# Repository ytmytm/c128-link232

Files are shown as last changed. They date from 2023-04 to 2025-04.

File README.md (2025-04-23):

These are boards for C128D/DCR internal WiFi modems based on the ACIA 6551 and Wemos D1 ESP8266 modules flashed with Zimodem firmware.

This work is heavily base on dabonetn's work from [Link232-Wifi](https://github.com/dabonetn/Link232-Wifi) project. Please go there for additional documentation.

# Installation

For both projects you need to decide on the interrupt source and address space. I recommend using `/NMI` as the interrupt and `$D700` as the base address.
This way, you can readily use most popular software for both C128 (DesTerm) and C64 (CCGMS), and the mod doesn't interfere with cartridges.

## Raise CIA

For both boards one of the CIA chips is raised to the daughterboard.

## Interrupt line

Both boards connect ACIA interrupt pin to local CIA chip but if it's not the right one (i.e. you want `/NMI` but the board is over CIA#1 which is connected to `/IRQ`) you need to run a wire to a suitable singal source from the mainboard.

## Base address

A signal for ACIA I/O address access in $D700-$D7FF area is readily available from U3 pin 12 that is otherwise unconnected.

## DotClock

Both boards require DotClock signal from the Expansion port pin 6.

# Swift-L (C128D)

This board is meant primarly for C128D and it is supposed to be plugged in place of CIA#2. It is a clone of [Link232 Swift-L](https://github.com/dabonetn/Link232-Wifi) project converted to Kicad6, with Burst connector added.

The `/NMI` signal is already available from the mainboard CIA#2 socket, so you only need to connect ACIA I/O signal and DotClock.

This board also features a 10-pin socket for a flat cable for burst connection to 1541 drives. The pinout is compatible with [DolphinDos3](https://e4aws.silverdr.com/projects/dolphindos3/) with `/FLAG` signal on pin 1, then 8 data lines and `/PC2` signal on pin 10. 

## C128DCR notes

There is not enough clearance under power supply on C128DCR to use that board with CIA#2, but this should fit in place of CIA#1.

You need to route `/NMI` interrupt line to pin 26 of ACIA 6551 somewhere from the board - the Expansion port pin D is the closet spot.

The burst connector would work correctly, but no software uses CIA#1 for that purpose.

## Swift-CIA3 (C128DCR)

This board is meant to be used in C128DCR over CIA#1. It has several features that I needed and you may find optional. If all you need is internal ACIA modem you should better use Swift-L variant.

You need to connect these external control signals to connector J1:

|pin|  |
|---|--|
|1|I/O signal for ACIA, for page $D700 connect to U3 pin 12|
|2|DotClock from Expansion port pin 6|
|3|Interrupt for ACIA, connect `/NMI` from Expansion port pin D|
|4|I/O signal for CIA#3 (optional)

In my case both ACIA I/O and CIA#3 I/O signals come from [U3 address decoder replaced by a GAL](https://github.com/ytmytm/c128-u3-replacement), so CIA#1 occupies addresses $DC00-$DC20 and CIA#3 appears in $DC20-$DC40

Connector J2 has a simple serial bus with GND/VCC/SP/CNT signals from CIA#3.

Connector J4 exposes CIA#3 port B so that it can be used to switch Kernal or Internal Function ROMs.

A jumper controls whether ACIA is connected to `/IRQ` (from CIA#1) or to `/NMI` (from J1 pin 3).

Another jumper selects 50/60Hz signal for TOD clock coming from ATTiny.

### CIA#3

CIA#3 is connected to ATA-IDE 40-pin connector for harddrives for [my CIAIDE project](https://github.com/ytmytm/c64-ciaide).
Port B lines are also connected to a pin header because they could be used for something like an internal ROM switcher.

### ATTiny85

There is a place for ATTiny85 to generate TOD clock signal.

In one of my C128DCRs I replaced power supply by a Mean Well RD35A power supply with 12V(1A)/5V(4A) rails. This runs much cooler than original power supply, but doesn't generate 9VAC. I don't mind the tape port as I don't use it anyway, but TOD clock is useful for GEOS.

Note that without 9VAC you need to replace CR8 by a wire (to short it to GND so that input to U16 pin 11 is not floating) and completely remove R7 and C80 elements.

**NOTE Don't use this sketch! Use the [more accurate code by fastjack](https://github.com/fastjack/attiny-clockgen)**

ATTiny runs this simple Arduino code to generate 50/60Hz waveform on TOD clock line, depending on jumper being open or closed:

```

// IDE: ATtiny25/45/85, internal 1MHz
// 1MHz is the default speed, no need to switch fuses to 8MHz
// compile to HEX (Sketch->Export compiled binary) and burn using TL866-II

// pinout
//   /RESET 1  U  8 5V
//   A3/PB3 2     7 A1/2/PB2
//   A2/PB4 3     6 PB1 PWM
//      GND 4     5 PB0 PWM -- output PWM 50Hz

const uint8_t PWM_pin = 0; // PB0, pin 5
const uint8_t mode_pin = 1; // PB1, pin 6 - jumper to GND for NTSC mode, keep floating (internal pullup) for PAL
uint8_t half_duty = 10;    // 10ms for PAL, 8ms for NTSC = 20ms/16ms

void setup() {
  pinMode(PWM_pin, OUTPUT);
  digitalWrite(PWM_pin, LOW);
  pinMode(mode_pin, INPUT_PULLUP);
  delay(200);
  if (digitalRead(mode_pin) == LOW) { // is it tied to GND?
    half_duty = 8;  // yes - switch to 8ms half duty cycle for 16ms ~ 62.5Hz frequency
  }
}

void loop() {
  // could be done using PWM and clock prescalers, but that is good enough for me
  while (true) {
    delay(half_duty); // 10ms - half of 20ms duty cycle
    digitalWrite(PWM_pin, HIGH);
    delay(half_duty); // 10ms - half of 20ms duty cycle
    digitalWrite(PWM_pin, LOW);
  }
}

```

# Zimodem - Wemos D1 firmware

Flash Wemos D1 with [Zimodem](https://github.com/bozimmerman/Zimodem) software.

I have compiled it with these settings:

Board: LOLIN(WEMOS) D1 R2 & Mini, 80MHz, flash 4MB (2MB FS, 1MB OTA), debug disabled, lwIP "v2 Lower Memory", Erase Flash: "Only sketch"

*Attention*: Check if this notice still exists in the README. If it does - make sure to downgrade Generic ESP8266 Library to version 2.7.4 in your Arduino IDE.

```
2.7.4 Arduino ESP8266 libraries using the Generic ESP8266 Module.  Versions newer than 2.7.4 may not work.
```

"May not work" in this case means that ESP8266 will keep crashing. You can test this still in Arduino IDE in the serial monitor.

*Attention*: Search for these defines and make these changes on the top of zimodem.ino before compiling:

1. Comment out this line to make RS232 lines non-inverted by default:
```
//# define RS232_INVERTED 1
```

2. Set default baud rate to 19200 (sensible choice for C64) or 38400 (maximum for ACIA)
```
#define DEFAULT_BAUD_RATE 19200
```

# C64/128 software

With these changes and ACIA setup to use `/NMI` at $D700 base address both latest version of CCGMS and DesTerm 128 will work fine.

Make sure that everything is setup correctly by issuing `AT` command. The modem should respond with `OK`.

Then start configuration menu by typing `AT+CONFIG`

By default RTS/CTS flow control is not enabled (so that operation can be checked in Arduino IDE serial monitor), so you should enable it with `ATF0` command because C64/128 will not keep up with scrolling the screen even in 19200 baud mode. You can save the settings to flash afterwards with `AT&W`.

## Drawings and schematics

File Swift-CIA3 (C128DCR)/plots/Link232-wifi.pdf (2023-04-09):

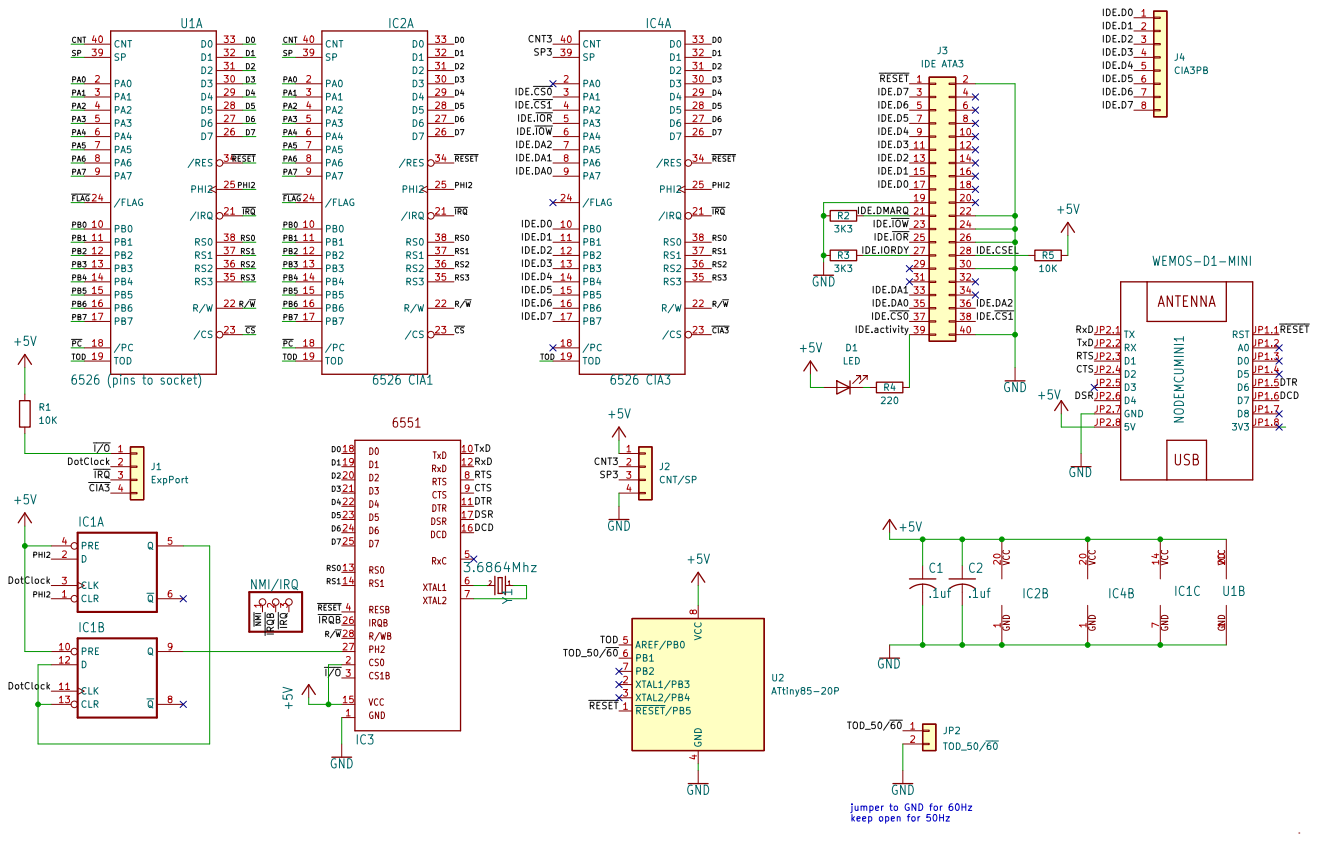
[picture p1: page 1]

jumper to GND for 60Hz
keep open for 50Hz

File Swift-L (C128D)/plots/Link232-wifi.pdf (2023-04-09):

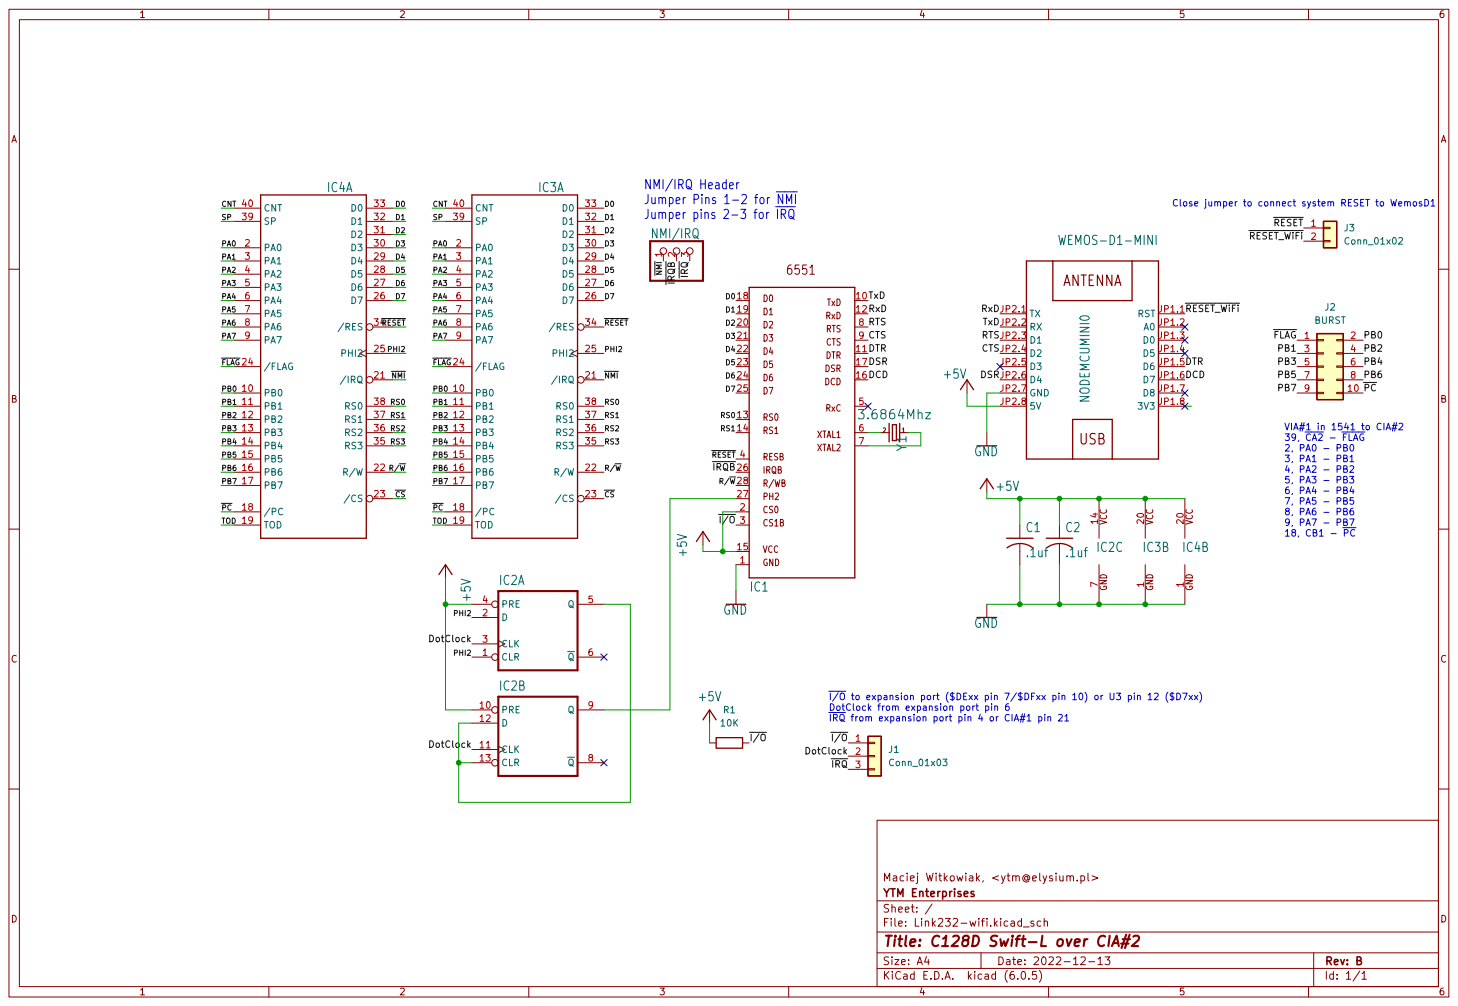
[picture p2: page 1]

Close jumper to connect system RESET to WemosD1
WEMOS-D1-MINI GND 14VCC

~{I/O} to expansion port ($DExx pin 7/$DFxx pin 10) or U3 pin 12 ($D7xx)
DotClock from expansion port pin 6
~{IRQ} from expansion port pin 4 or CIA#1 pin 21

File: Link232-wifi.kicad_sch Sheet: / YTM Enterprises

Id: 1/1 Title: C128D Swift-L over CIA#2

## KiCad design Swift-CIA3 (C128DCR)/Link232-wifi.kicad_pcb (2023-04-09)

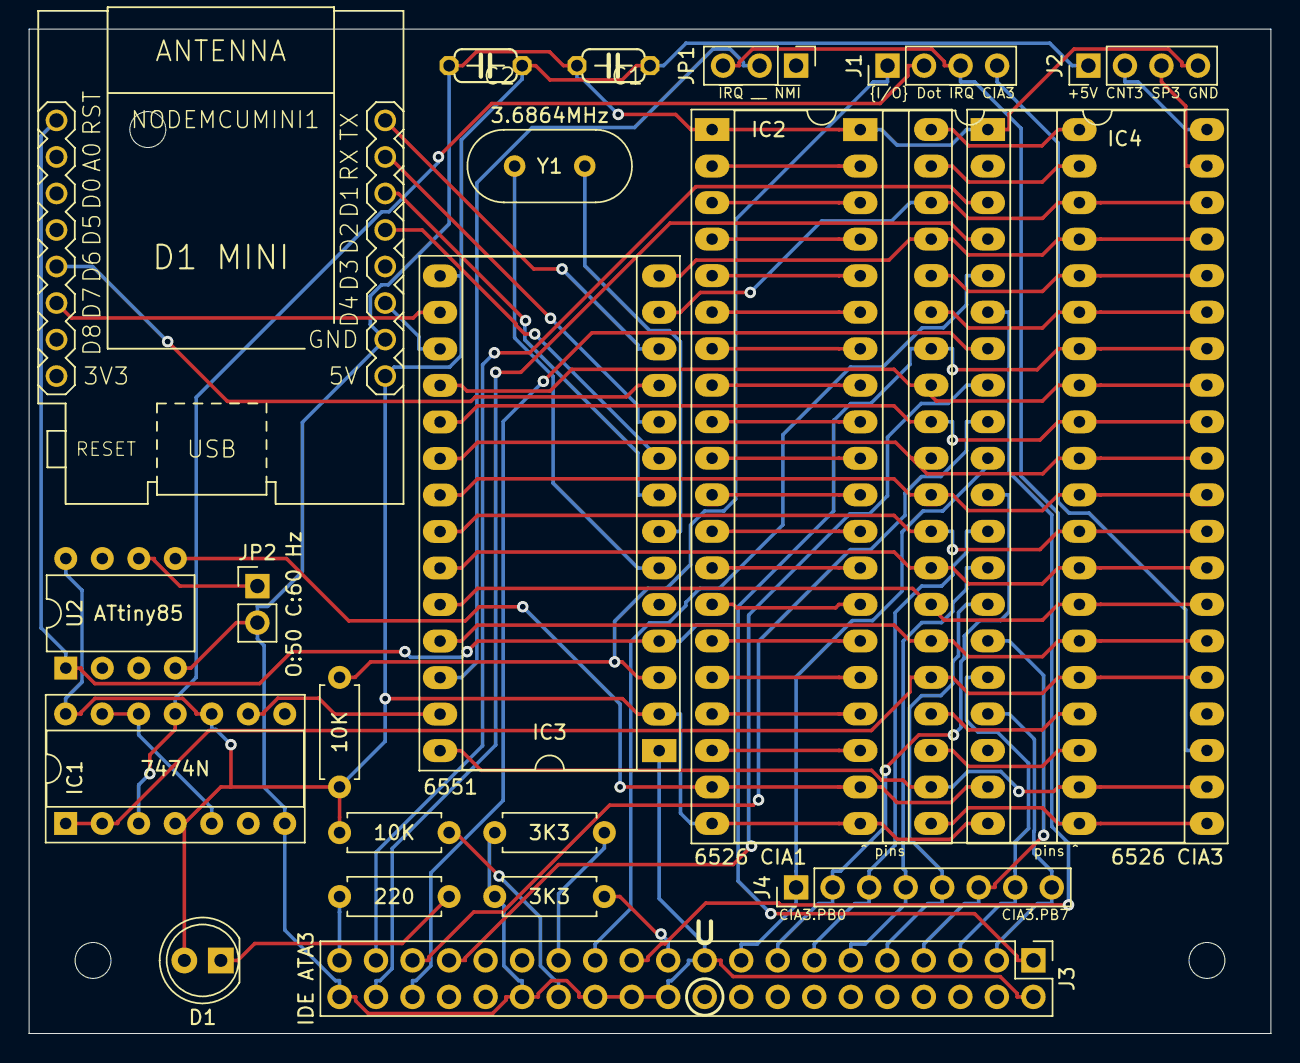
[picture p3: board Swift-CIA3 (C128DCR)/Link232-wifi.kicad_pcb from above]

Board: 2 copper layers, 86.4 x 69.8 mm, 25 parts (0 on the bottom side), 78 nets.

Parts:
C1, C2: .1uf; C050-024X044
D1: LED; LED_D5.0mm
IC1: 7474N; DIP-14_W7.62mm_Socket
IC2: 6526 CIA1; DIP-40_W15.24mm_Socket_LongPads
IC3: 6551; DIP-28_W15.24mm_Socket_LongPads
IC4: 6526 CIA3; DIP-40_W15.24mm_Socket_LongPads
J1: {I/O} Dot ~{IRQ} ~{CIA3}; PinHeader_1x04_P2.54mm_Vertical
J2: +5V CNT3 SP3 GND; PinHeader_1x04_P2.54mm_Vertical
J3: IDE ATA3; PinHeader_2x20_P2.54mm_Vertical
J4: CIA3PB; PinHeader_1x08_P2.54mm_Vertical
JP1: ~{IRQ} __ ~{NMI}; PinHeader_1x03_P2.54mm_Vertical
JP2: O:50 C:60 Hz; PinHeader_1x02_P2.54mm_Vertical
NODEMCUMINI1: WEMOS-D1-MINI
R1, R5: 10K; R_Axial_DIN0207_L6.3mm_D2.5mm_P7.62mm_Horizontal
R2, R3: 3K3; R_Axial_DIN0207_L6.3mm_D2.5mm_P7.62mm_Horizontal
R4: 220; R_Axial_DIN0207_L6.3mm_D2.5mm_P7.62mm_Horizontal
REF1, REF2, REF3: MountingHole_2.5mm
U1: 6526 (pins to socket); DIP-40_W15.24mm_LongPads
U2: ATtiny85; DIP-8_W7.62mm
Y1: 3.6864MHz; Crystal_HC49-4H_Vertical

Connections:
+5V: C1.1, C2.1, D1.2 (A), IC1.4 (PRE), IC1.10 (PRE), IC1.14 (VCC), IC2.20 (VCC), IC3.2, IC3.15, IC4.20 (VCC), J2.1, NODEMCUMINI1.JP2.8 (5V), R1.1, R5.2, U1.20 (VCC), U2.8 (VCC)
/CNT: IC2.40 (CNT), U1.40 (CNT)
/CNT3: IC4.40 (CNT), J2.2
/CTS: IC3.9, NODEMCUMINI1.JP2.4 (D2)
/D0: IC2.33 (D0), IC3.18, IC4.33 (D0), U1.33 (D0)
/D1: IC2.32 (D1), IC3.19, IC4.32 (D1), U1.32 (D1)
/D2: IC2.31 (D2), IC3.20, IC4.31 (D2), U1.31 (D2)
/D3: IC2.30 (D3), IC3.21, IC4.30 (D3), U1.30 (D3)
/D4: IC2.29 (D4), IC3.22, IC4.29 (D4), U1.29 (D4)
/D5: IC2.28 (D5), IC3.23, IC4.28 (D5), U1.28 (D5)
/D6: IC2.27 (D6), IC3.24, IC4.27 (D6), U1.27 (D6)
/D7: IC2.26 (D7), IC3.25, IC4.26 (D7), U1.26 (D7)
/DCD: IC3.16, NODEMCUMINI1.JP1.6 (D7)
/DSR: IC3.17, NODEMCUMINI1.JP2.6 (D4)
/DTR: IC3.11, NODEMCUMINI1.JP1.5 (D6)
/DotClock: IC1.3 (CLK), IC1.11 (CLK), J1.2
/IDE.CSEL: J3.28, R5.1
/IDE.D0: IC4.10 (PB0), J3.17, J4.1
/IDE.D1: IC4.11 (PB1), J3.15, J4.2
/IDE.D2: IC4.12 (PB2), J3.13, J4.3
/IDE.D3: IC4.13 (PB3), J3.11, J4.4
/IDE.D4: IC4.14 (PB4), J3.9, J4.5
/IDE.D5: IC4.15 (PB5), J3.7, J4.6
/IDE.D6: IC4.16 (PB6), J3.5, J4.7
/IDE.D7: IC4.17 (PB7), J3.3, J4.8
/IDE.DA0: IC4.9 (PA7), J3.35
/IDE.DA1: IC4.8 (PA6), J3.33
/IDE.DA2: IC4.7 (PA5), J3.36
/IDE.DMARQ: J3.21, R2.2
/IDE.IORDY: J3.27, R3.2
/IDE.activity: J3.39, R4.2
/IDE.~CS0: IC4.3 (PA1), J3.37
/IDE.~CS1: IC4.4 (PA2), J3.38
/IDE.~IOR: IC4.5 (PA3), J3.25
/IDE.~IOW: IC4.6 (PA4), J3.23
/PA0: IC2.2 (PA0), U1.2 (PA0)
/PA1: IC2.3 (PA1), U1.3 (PA1)
/PA2: IC2.4 (PA2), U1.4 (PA2)
/PA3: IC2.5 (PA3), U1.5 (PA3)
/PA4: IC2.6 (PA4), U1.6 (PA4)
/PA5: IC2.7 (PA5), U1.7 (PA5)
/PA6: IC2.8 (PA6), U1.8 (PA6)
/PA7: IC2.9 (PA7), U1.9 (PA7)
/PB0: IC2.10 (PB0), U1.10 (PB0)
/PB1: IC2.11 (PB1), U1.11 (PB1)
/PB2: IC2.12 (PB2), U1.12 (PB2)
/PB3: IC2.13 (PB3), U1.13 (PB3)
/PB4: IC2.14 (PB4), U1.14 (PB4)
/PB5: IC2.15 (PB5), U1.15 (PB5)
/PB6: IC2.16 (PB6), U1.16 (PB6)
/PB7: IC2.17 (PB7), U1.17 (PB7)
/PHI2: IC1.1 (CLR), IC1.2 (D), IC2.25 (PHI2), IC4.25 (PHI2), U1.25 (PHI2)
/RS0: IC2.38 (RS0), IC3.13, IC4.38 (RS0), U1.38 (RS0)
/RS1: IC2.37 (RS1), IC3.14, IC4.37 (RS1), U1.37 (RS1)
/RS2: IC2.36 (RS2), IC4.36 (RS2), U1.36 (RS2)
/RS3: IC2.35 (RS3), IC4.35 (RS3), U1.35 (RS3)
/RTS: IC3.8, NODEMCUMINI1.JP2.3 (D1)
/RxD: IC3.12, NODEMCUMINI1.JP2.1 (TX)
/R/~W: IC2.22 (R/W), IC3.28, IC4.22 (R/W), U1.22 (R/W)
/SP: IC2.39 (SP), U1.39 (SP)
/SP3: IC4.39 (SP), J2.3
/TOD: IC2.19 (TOD), IC4.19 (TOD), U1.19 (TOD), U2.5 (AREF/PB0)
/TOD_50/~60: JP2.1, U2.6 (PB1)
/TxD: IC3.10, NODEMCUMINI1.JP2.2 (RX)
/~CIA3: IC4.23 (/CS), J1.4
/~CS: IC2.23 (/CS), U1.23 (/CS)
/~FLAG: IC2.24 (/FLAG), U1.24 (/FLAG)
/~IRQB: IC3.26, JP1.2
/~IRQ: IC2.21 (/IRQ), IC4.21 (/IRQ), J1.3, JP1.3, U1.21 (/IRQ)
/~I/O: IC3.3, J1.1, R1.2
/~PC: IC2.18 (/PC), U1.18 (/PC)
/~RESET: IC2.34 (/RES), IC3.4, IC4.34 (/RES), J3.1, NODEMCUMINI1.JP1.1 (RST), U1.34 (/RES), U2.1 (~RESET/PB5)
GND: C1.2, C2.2, IC1.7 (GND), IC2.1 (GND), IC3.1, IC4.1 (GND), J2.4, J3.2, J3.19, J3.22, J3.24, J3.26, J3.30, J3.40, JP2.2, NODEMCUMINI1.JP2.7 (GND), R2.1, R3.1, U1.1 (GND), U2.4 (GND)
unnamed: D1.1 (K), R4.1
unnamed: IC1.9 (Q), IC3.27
unnamed: IC1.5 (Q), IC1.12 (D), IC1.13 (CLR)
unnamed: IC3.6, Y1.2
unnamed: IC3.7, Y1.1

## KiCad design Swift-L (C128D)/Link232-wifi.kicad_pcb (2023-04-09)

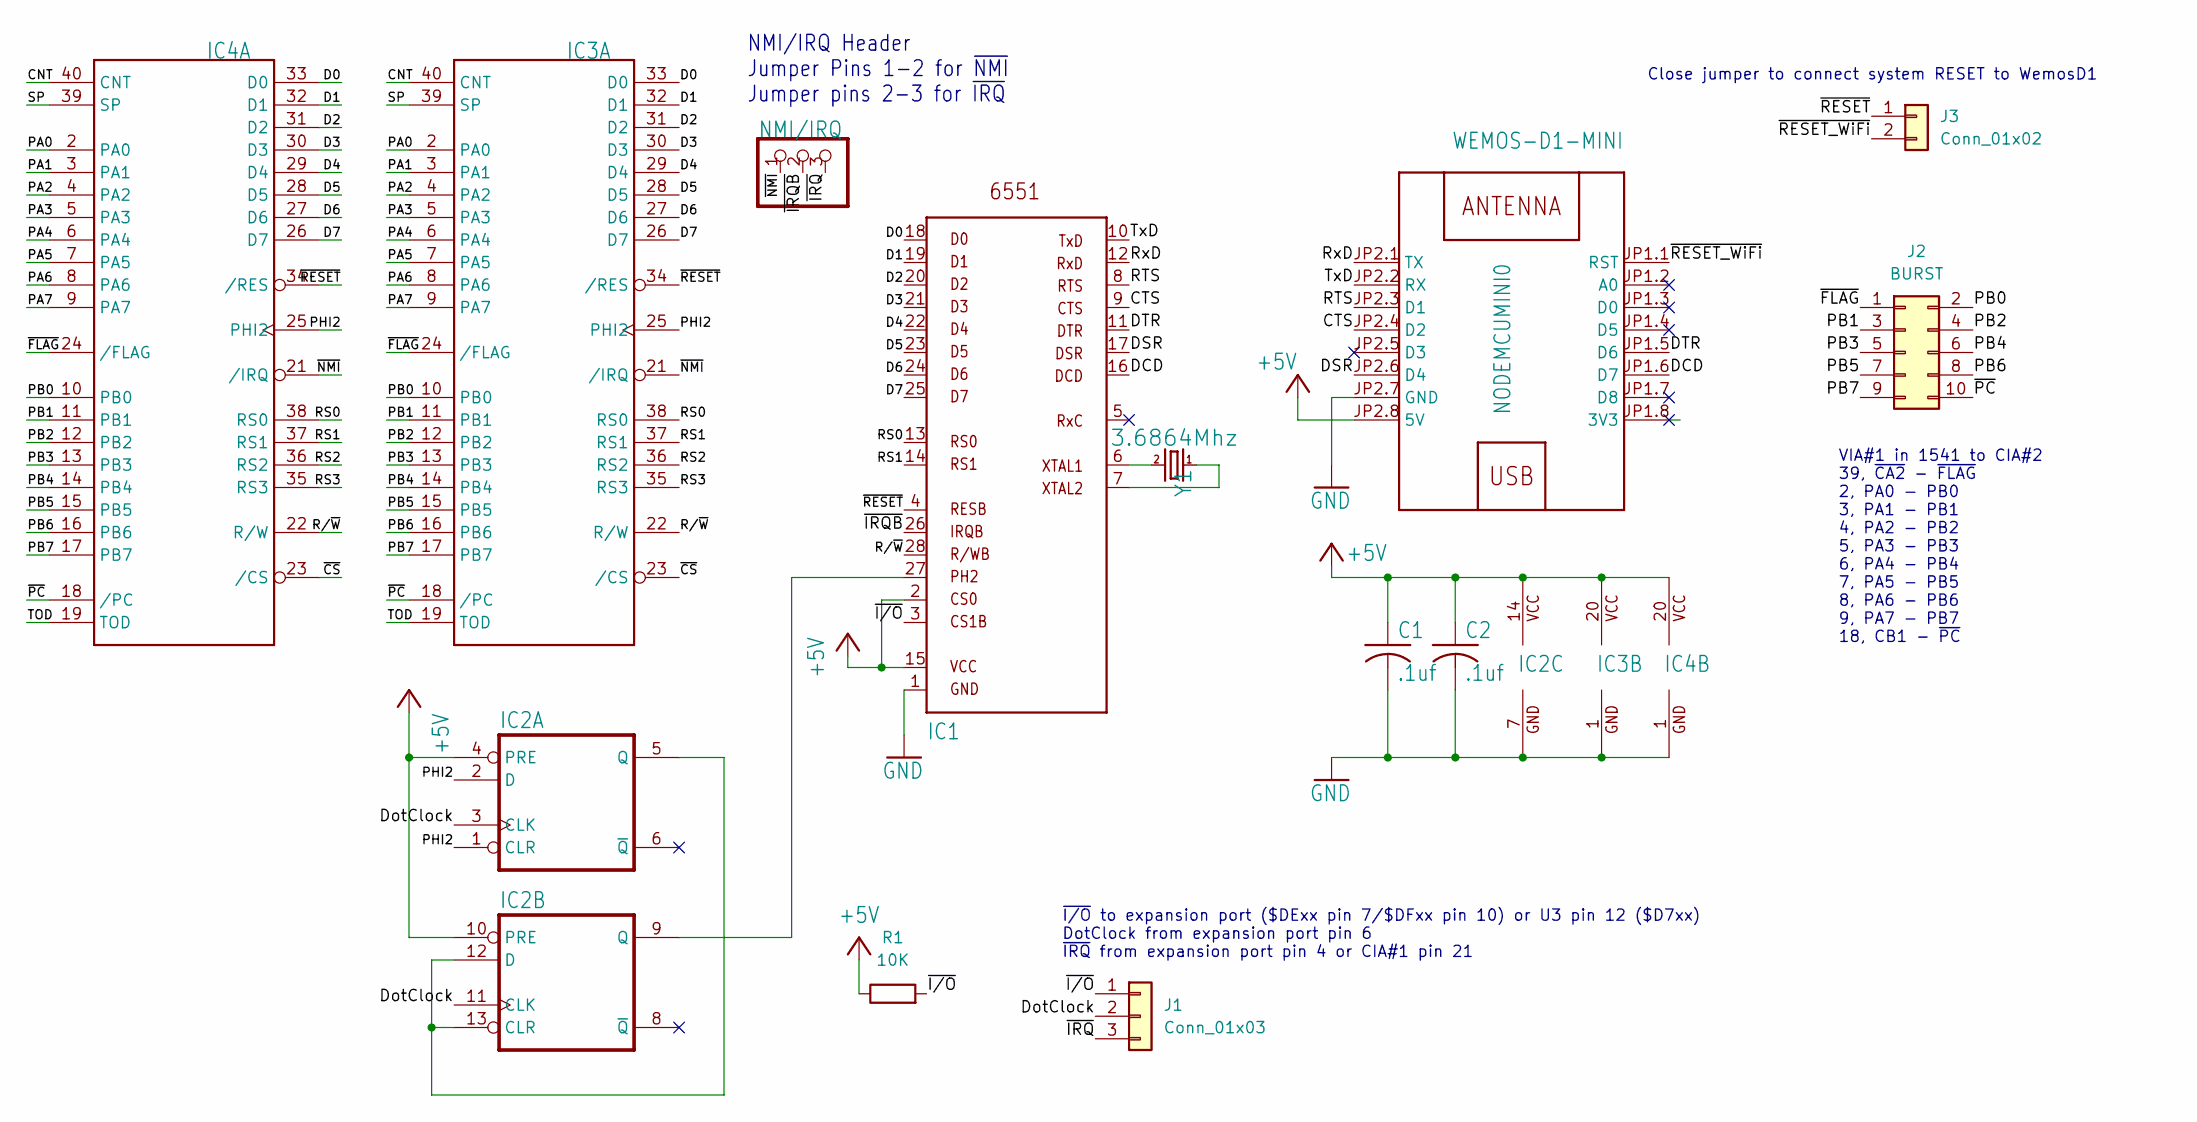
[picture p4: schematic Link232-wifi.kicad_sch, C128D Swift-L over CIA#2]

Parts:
C1, C2: .1uf; C050-024X044
IC1: 6551; DIP-28_W15.24mm_Socket_LongPads
IC2: 7474N; DIP-14_W7.62mm_Socket_LongPads
IC3: 6526; DIP-40_W15.24mm_Socket_LongPads
IC4: 6526; DIP-40_W15.24mm_LongPads
J1: Conn_01x03; PinHeader_1x03_P2.54mm_Vertical
J2: BURST; PinHeader_2x05_P2.54mm_Vertical
J3: Conn_01x02; PinHeader_1x02_P2.54mm_Vertical
JP1: NMI/IRQ; PinHeader_1x03_P2.54mm_Vertical
NODEMCUMINI0: WEMOS-D1-MINI
R1: 10K; R_Axial_DIN0207_L6.3mm_D2.5mm_P10.16mm_Horizontal
Y1: 3.6864Mhz; Crystal_HC49-4H_Vertical

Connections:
+5V: C1.1, C2.1, IC1.2, IC1.15, IC2.4 (PRE), IC2.10 (PRE), IC2.14 (VCC), IC3.20 (VCC), IC4.20 (VCC), NODEMCUMINI0.JP2.8 (5V), R1.1
/CNT: IC3.40 (CNT), IC4.40 (CNT)
/CTS: IC1.9, NODEMCUMINI0.JP2.4 (D2)
/D0: IC1.18, IC3.33 (D0), IC4.33 (D0)
/D1: IC1.19, IC3.32 (D1), IC4.32 (D1)
/D2: IC1.20, IC3.31 (D2), IC4.31 (D2)
/D3: IC1.21, IC3.30 (D3), IC4.30 (D3)
/D4: IC1.22, IC3.29 (D4), IC4.29 (D4)
/D5: IC1.23, IC3.28 (D5), IC4.28 (D5)
/D6: IC1.24, IC3.27 (D6), IC4.27 (D6)
/D7: IC1.25, IC3.26 (D7), IC4.26 (D7)
/DCD: IC1.16, NODEMCUMINI0.JP1.6 (D7)
/DSR: IC1.17, NODEMCUMINI0.JP2.6 (D4)
/DTR: IC1.11, NODEMCUMINI0.JP1.5 (D6)
/DotClock: IC2.3 (CLK), IC2.11 (CLK), J1.2
/PA0: IC3.2 (PA0), IC4.2 (PA0)
/PA1: IC3.3 (PA1), IC4.3 (PA1)
/PA2: IC3.4 (PA2), IC4.4 (PA2)
/PA3: IC3.5 (PA3), IC4.5 (PA3)
/PA4: IC3.6 (PA4), IC4.6 (PA4)
/PA5: IC3.7 (PA5), IC4.7 (PA5)
/PA6: IC3.8 (PA6), IC4.8 (PA6)
/PA7: IC3.9 (PA7), IC4.9 (PA7)
/PB0: IC3.10 (PB0), IC4.10 (PB0), J2.2
/PB1: IC3.11 (PB1), IC4.11 (PB1), J2.3
/PB2: IC3.12 (PB2), IC4.12 (PB2), J2.4
/PB3: IC3.13 (PB3), IC4.13 (PB3), J2.5
/PB4: IC3.14 (PB4), IC4.14 (PB4), J2.6
/PB5: IC3.15 (PB5), IC4.15 (PB5), J2.7
/PB6: IC3.16 (PB6), IC4.16 (PB6), J2.8
/PB7: IC3.17 (PB7), IC4.17 (PB7), J2.9
/PHI2: IC2.1 (CLR), IC2.2 (D), IC3.25 (PHI2), IC4.25 (PHI2)
/RS0: IC1.13, IC3.38 (RS0), IC4.38 (RS0)
/RS1: IC1.14, IC3.37 (RS1), IC4.37 (RS1)
/RS2: IC3.36 (RS2), IC4.36 (RS2)
/RS3: IC3.35 (RS3), IC4.35 (RS3)
/RTS: IC1.8, NODEMCUMINI0.JP2.3 (D1)
/RxD: IC1.12, NODEMCUMINI0.JP2.1 (TX)
/R/~W: IC1.28, IC3.22 (R/W), IC4.22 (R/W)
/SP: IC3.39 (SP), IC4.39 (SP)
/TOD: IC3.19 (TOD), IC4.19 (TOD)
/TxD: IC1.10, NODEMCUMINI0.JP2.2 (RX)
/~CS: IC3.23 (/CS), IC4.23 (/CS)
/~FLAG: IC3.24 (/FLAG), IC4.24 (/FLAG), J2.1
/~IRQB: IC1.26, JP1.2
/~IRQ: J1.3, JP1.3
/~I/O: IC1.3, J1.1, R1.2
/~NMI: IC3.21 (/IRQ), IC4.21 (/IRQ), JP1.1
/~PC: IC3.18 (/PC), IC4.18 (/PC), J2.10
/~RESET_WiFi: J3.2, NODEMCUMINI0.JP1.1 (RST)
/~RESET: IC1.4, IC3.34 (/RES), IC4.34 (/RES), J3.1
GND: C1.2, C2.2, IC1.1, IC2.7 (GND), IC3.1 (GND), IC4.1 (GND), NODEMCUMINI0.JP2.7 (GND)
unnamed: IC1.6, Y1.2
unnamed: IC1.7, Y1.1
unnamed: IC1.27, IC2.9 (Q)
unnamed: IC2.5 (Q), IC2.12 (D), IC2.13 (CLR)

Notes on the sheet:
NMI/IRQ Header Jumper Pins 1-2 for ~{NMI} Jumper pins 2-3 for ~{IRQ}
Close jumper to connect system RESET to WemosD1
~{I/O} to expansion port ($DExx pin 7/$DFxx pin 10) or U3 pin 12 ($D7xx) DotClock from expansion port pin 6 ~{IRQ} from expansion port pin 4 or CIA#1 pin 21
VIA#1 in 1541 to CIA#2 39, ~{CA2} - ~{FLAG} 2, PA0 - PB0 3, PA1 - PB1 4, PA2 - PB2 5, PA3 - PB3 6, PA4 - PB4 7, PA5 - PB5 8, PA6 - PB6 9, PA7 - PB7 18, CB1 - ~{PC}

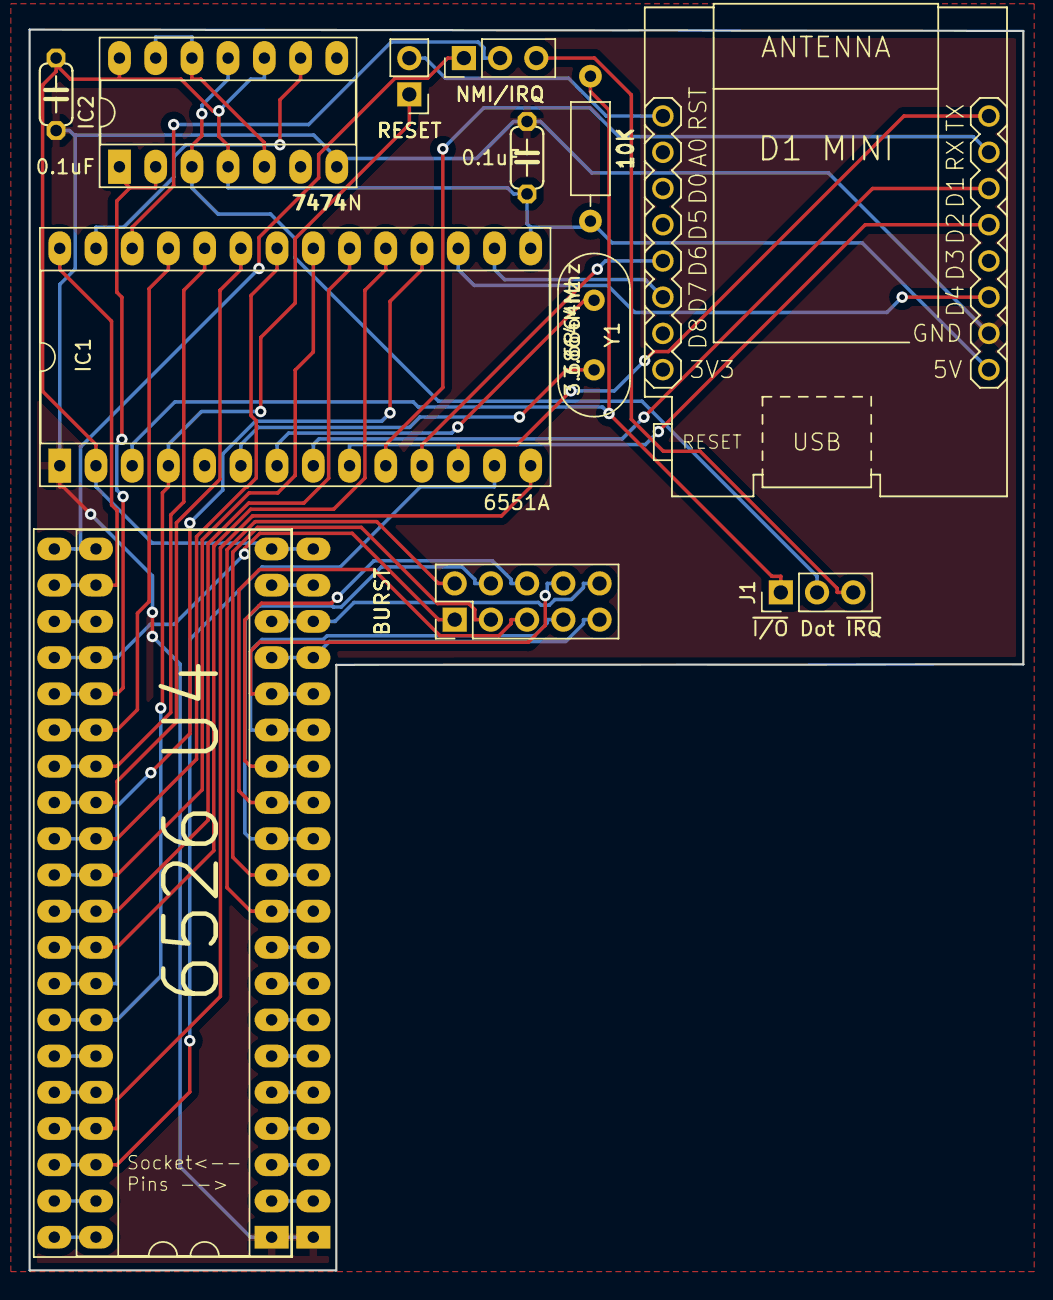
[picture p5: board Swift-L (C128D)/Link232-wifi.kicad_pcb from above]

Board: 2 copper layers, 69.7 x 87.0 mm, 13 parts (0 on the bottom side), 56 nets.
